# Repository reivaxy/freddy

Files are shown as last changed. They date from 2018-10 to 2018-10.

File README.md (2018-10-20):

# freddy

My goal was to design a set of pieces that are easy to print (no support is needed), and easy to assemble in order to build Freddy Krueger's famous clawed glove, so the design is simplified.

The claws (or blades) should be printed with grey or silver-like filament, and the finger pieces in brownish or bronze filament.

Each finger can be easily parametered with 2 diameters for each half finger, the lenghts of upper and lower fingers, and the length and width of the band to tie the finger to the hand plate.

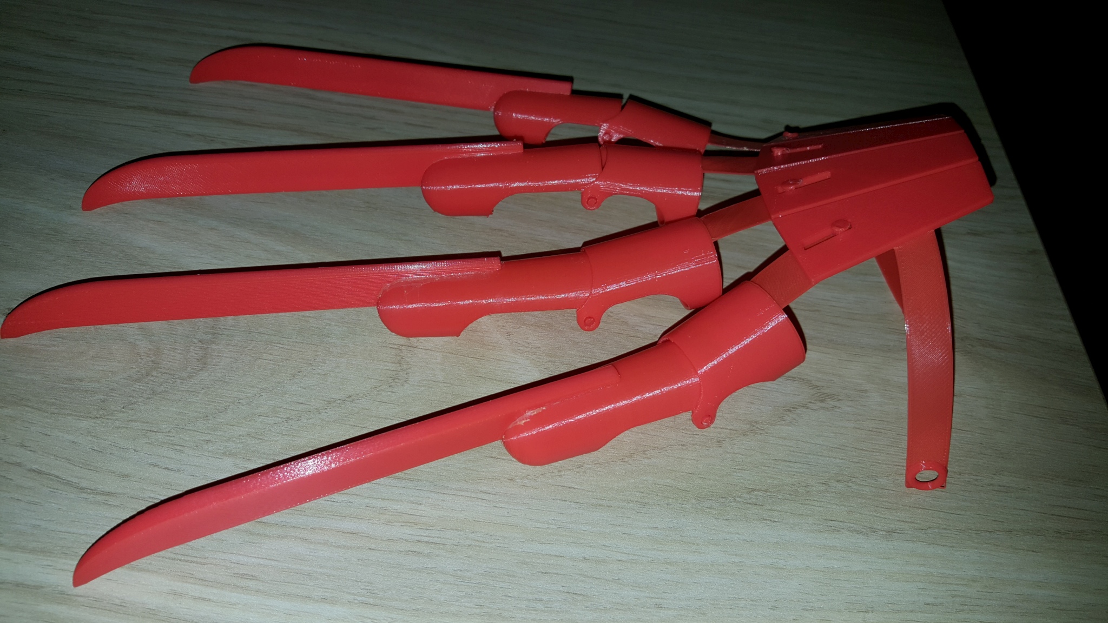
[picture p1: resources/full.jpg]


Here is the final print, using grey and bronze PLA, and wiping some acrylic paint on it so that it does not look to new.

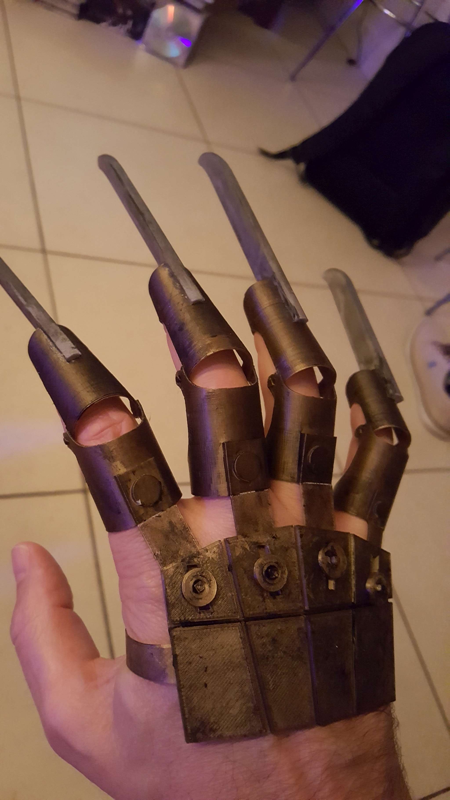
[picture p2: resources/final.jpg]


Admittedly, the sweater needs some work :)

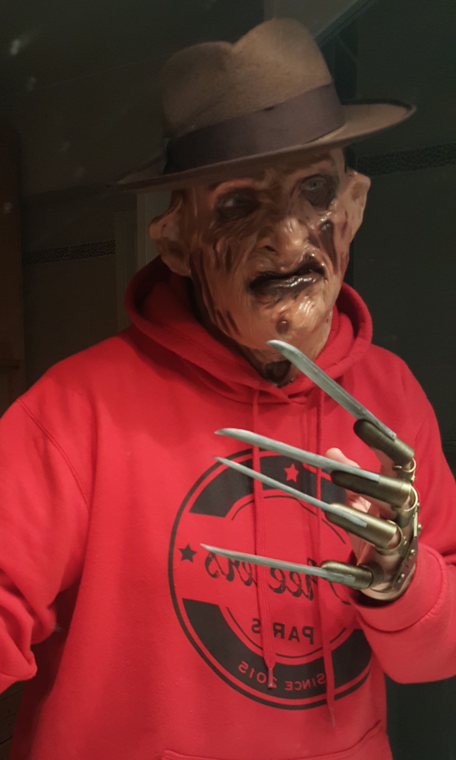
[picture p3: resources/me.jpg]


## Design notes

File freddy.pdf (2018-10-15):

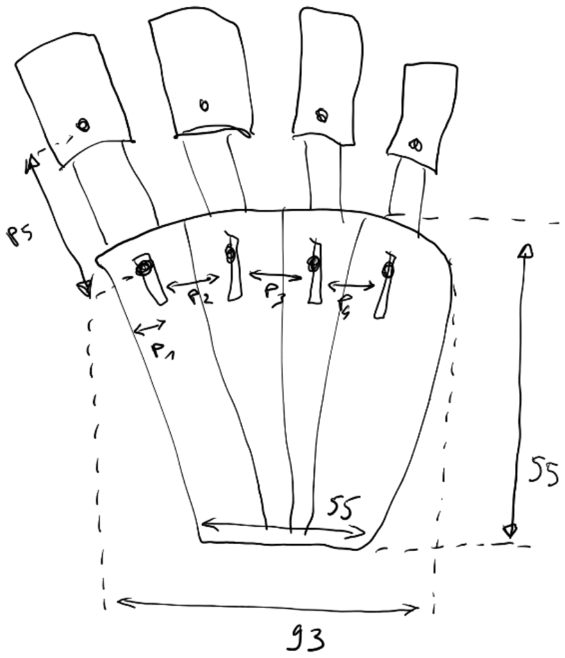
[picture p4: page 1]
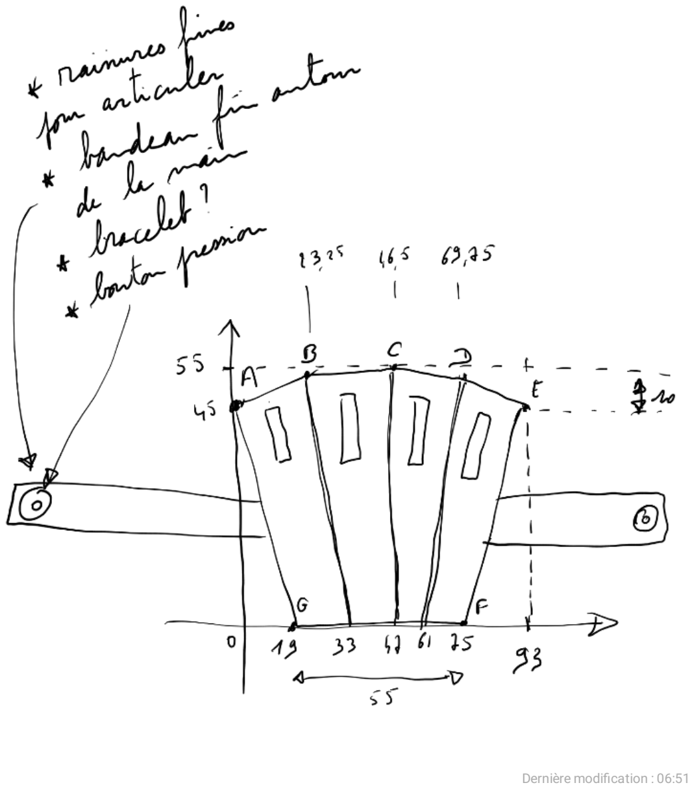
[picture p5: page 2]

Dernière modification : 06:51

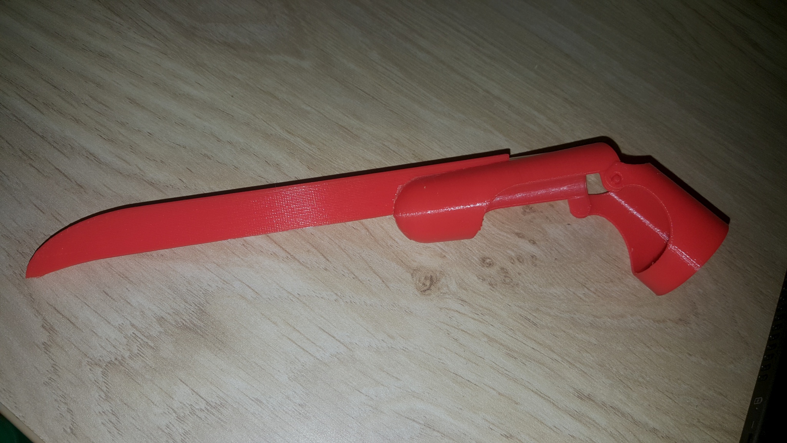
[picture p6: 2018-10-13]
resources/freddy.jpg

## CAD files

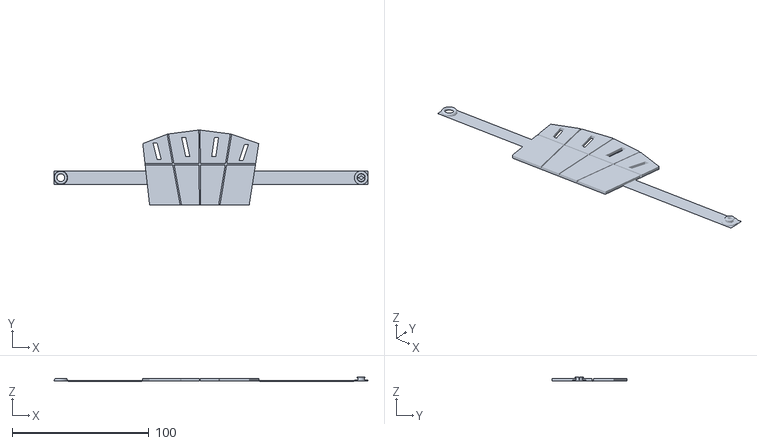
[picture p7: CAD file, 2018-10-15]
hand.stl
230.0 x 55.0 x 3.25

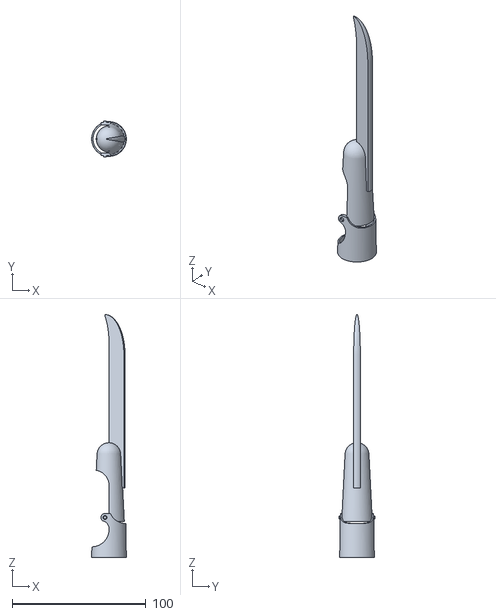
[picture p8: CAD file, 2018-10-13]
finger.stl
26.0 x 27.0 x 182.0

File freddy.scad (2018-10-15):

use <snapButton.scad>;

fingers();
translate([-50, -150, 0])
  handPlate();

module fingers() {
  translate([0, -70, 0])
    index();
  translate([0, -25, 0])
    majeur();
  translate([0, 20, 0])
    annulaire();
  translate([0, 65, 0])
    auriculaire();
}

// lowerBottomDiam, lowerTopDiam, lowerLength,
//          upperBottomDiam, upperTopDiam, upperLength,
//               join band width, join band length
module auriculaire() {
  printableFinger(20, 17, 33, 16, 15, 33, 8);
}
module annulaire() {
  printableFinger(23, 20, 34, 20, 16, 44);
}
module majeur() {
  printableFinger(24, 23, 40, 22, 16, 50);
}
module index() {
  printableFinger(24, 22, 33, 21, 16, 44);
  //finger(24, 23, 33, 21, 16, 44);
}

// thin band to join the base of each finger to the hand top plate
module join(width, length) {
  pinWidth = 2.5;
  color("yellow") {
    cube([length - width/2, width, 0.3]);
    translate([length - width/2, width/2, 0])
      cylinder(d=width, h=0.3, $fn=40);
    translate([length - 2*pinWidth, (width - pinWidth)/2, 0])
      cube([pinWidth, pinWidth, 6]);
  }

  // button to block it
  // snapButtonFemale(baseDiam, baseH, pinDiam, pinZ, tolerance=0.3)
  translate([length + 10 , width/2, 0])
   snapButtonFemale(10, 1.8, pinWidth, 3, tolerance=0.2);
}

module handPlate() {
  z = 2;
  zThin = 0.3;
  A = [5, 45];
  B = [23.25, 52];
  C = [46.5, 55];
  D = [69.75, 52];
  E = [90, 45];
  F = [83,0];
  G = [10, 0];
  difference() {
    linear_extrude(z)
      polygon([A, B, C, D, E, F, G]);

    // Creases for articulation
    crease(zThin, 1, B, [33, 0]);
    crease(zThin, 1, C, [47, 0]);
    crease(zThin, 1, D, [61, 0]);
    translate([0, 30, 0])
      rotate(90, [0, 0, -1])
        crease(zThin, 1, [0, 0], [0, 100]);

    // Creases for mobile finger joins
    crease(0, 3, [14,44], [17, 35]);
    crease(0, 3, [35,48], [38, 37]);
    crease(0, 3, [59,48], [57, 37]);
    crease(0, 3, [81,43], [77, 34]);
  }
  translate([-60, 15])
    wristBand(10, 230);
}

module crease(thin, width, topPoint, bottomPoint) {
  topPointLeft = [topPoint[0] - width/2, topPoint[1] + width/2];
  topPointRight = [topPoint[0] + width/2, topPoint[1] + width/2];
  bottomPointLeft = [bottomPoint[0] - width/2, bottomPoint[1] - width/2];
  bottomPointRight = [bottomPoint[0] + width/2, bottomPoint[1] - width/2];
  translate([0, 0, thin]) {
    linear_extrude(10) {
      polygon([topPointLeft, topPointRight, bottomPointRight, bottomPointLeft]);
    }
  }
}

thickness = 1;
hingeDiam = 3;
module printableFinger(lowerBottomDiam, lowerTopDiam, lowerLength,
                       upperBottomDiam, upperTopDiam, upperLength, joinWidth=13, joinLength=27) {

  //upperFinger(upperBottomDiam, upperTopDiam, upperLength, thickness, hingeDiam);
  translate([lowerBottomDiam + 5, 0, 0])
    lowerFinger(lowerBottomDiam, lowerTopDiam, lowerLength, thickness, hingeDiam, joinWidth, joinLength);
  translate([-40, 15, 0])
  rotate(90, [0, 0, 1])
  rotate(-10, [0, 1, 0])
  rotate(90, [1, 0, 0])
    claw(upperBottomDiam, upperTopDiam, upperLength);
}

module finger(lowerBottomDiam, lowerTopDiam, lowerLength,
                        upperBottomDiam, upperTopDiam, upperLength, joinWidth=13, joinLength=35) {
  lowerFinger(lowerBottomDiam, lowerTopDiam, lowerLength, thickness, hingeDiam, joinWidth, joinLength);
  translate([0, 0, lowerLength - 2* hingeDiam])
    upperFinger(upperBottomDiam, upperTopDiam, upperLength, thickness, hingeDiam);
  translate([-3, 0, upperLength+2])
    claw(upperBottomDiam, upperTopDiam, upperLength);
}

module claw(upperBottomDiam, upperTopDiam, upperLength) {
  difference() {
    rotate(90, [0, 0, 1]) {
      difference() {
        clawCore();
        translate([0, 12, 0])
          scale([3, 1, 1.09])
          clawCore();
        rotate(10, [0, 0, 1]) {
          translate([0, -20, 0])
            cube([20, 40, 150]);
        }
        rotate(-10, [0, 0, 1]) {
          translate([-20, -20, 0])
            cube([20, 40, 150]);
        }
      }
    }
    translate([2.6, 0, -upperLength/2]) {
      outerBottomDiameter = upperBottomDiam + 2* thickness;
      outerTopDiameter = upperTopDiam + 2* thickness;
      cylinder(d1 = outerBottomDiameter, d2 = outerTopDiameter, h = upperLength, $fn=50);
      // Top sphere
      translate([0, 0, upperLength]) {
        sphere(d=outerTopDiameter, $fn=50);
      }
    }
  }
}

module clawCore() {
  scale([1, 2, 1]) {
    translate([0, 0, 100])
      scale([1, 1, 4])
        sphere(d=15, $fn=100);
    cylinder(d=15, h=100, $fn=100);
  }
}

module upperFinger(innerBottomDiameter, innerTopDiameter, upperLength, thickness, hingeDiameter) {
  outerBottomDiameter = innerBottomDiameter + 2* thickness;
  outerTopDiameter = innerTopDiameter + 2* thickness;

  difference() {
    cylinder(d1 = outerBottomDiameter, d2 = outerTopDiameter, h = upperLength, $fn=100);
    cylinder(d1 = innerBottomDiameter, d2 = innerTopDiameter, h = upperLength, $fn=100);
    // Cut half of cylinder
    translate([-outerBottomDiameter, -outerBottomDiameter/2, 0]) {
      cube([outerBottomDiameter, outerBottomDiameter, upperLength - outerBottomDiameter]);
    }
    // Top of cut is rounded, which eases printing with no support
    color("blue")
    translate([-outerBottomDiameter/2, outerBottomDiameter/2, upperLength - outerBottomDiameter]) {
      rotate(90, [1, 0, 0]) {
        cylinder(d=outerBottomDiameter, h=outerBottomDiameter, $fn=100);
      }
    }
  }
  // Top sphere
  translate([0, 0, upperLength]) {
    difference() {
      sphere(d=outerTopDiameter, $fn=50);
      sphere(d=innerTopDiameter, $fn=50);
      // Cut lower half of sphere
      translate([-outerTopDiameter/2, -outerTopDiameter/2, -outerTopDiameter]) {
        cube(outerTopDiameter);
      }
    }
  }
  // Hinges to connect lower finger
  hingeSide = hingeDiameter * 2;
  translate([-hingeSide, -outerBottomDiameter/2, 0]) {
    difference() {
      union() {
        translate([hingeSide/2, 0, 0]) {
          cube([hingeSide/2, outerBottomDiameter, hingeSide]);
        }
        translate([hingeSide/2, outerBottomDiameter, hingeSide/2]) {
          rotate(90, [1, 0, 0]) {
            cylinder(d=hingeSide, h=outerBottomDiameter, $fn=100);
          }
        }
        hingeLength = 2;
        translate([hingeSide/2, outerBottomDiameter + hingeLength, hingeSide/2]) {
          rotate(90, [1, 0, 0]) {
            cylinder(d=hingeDiameter - 0.5, h=outerBottomDiameter + hingeLength*2, $fn=100);
          }
        }

      }
      translate([0, thickness, 0]) {
        cube([hingeSide, innerBottomDiameter, hingeSide*2]);
      }
    }
  }
}


module lowerFinger(innerBottomDiameter, innerTopDiameter, lowerLength,
                         thickness, hingeDiameter, joinWidth, joinLength) {
  outerBottomDiameter = innerBottomDiameter + 2* thickness;
  outerTopDiameter = innerTopDiameter + 2* thickness;

  difference() {
    union() {
      cylinder(d1 = outerBottomDiameter, d2 = outerTopDiameter, h = lowerLength, $fn=100);

      // Flat zone to attach the band to join the hand plate
      translate([0, -joinWidth/2, 0]) {
        color("blue")
        cube([outerBottomDiameter/2, joinWidth, joinWidth + 3]);
        // Add a fake rivet on the flat zone
        translate([outerBottomDiameter/2, joinWidth/2, (joinWidth + 3)/2])
          rotate(90, [0, 1, 0])
            cylinder(d=joinWidth*0.7, h=1, $fn=50);
      }
      // band to join the hand plate
      translate([outerBottomDiameter/2, -joinWidth/2, 0]) {
        join(joinWidth, joinLength);
      }
    }
    cylinder(d1 = innerBottomDiameter, d2 = innerTopDiameter, h = lowerLength, $fn=100);

    // Rounded cut in cylinder lower half, inner-hand
    color("red")
    translate([-outerBottomDiameter/2, outerBottomDiameter/2 + 5, lowerLength/5 + outerBottomDiameter/2]) {
      rotate(90, [1, 0, 0]) {
        cylinder(d = outerBottomDiameter, h = outerBottomDiameter + 10, $fn=100);
      }
    }
    // Remove cylinder inner-hand upper half
    color("blue")
    translate([-outerBottomDiameter, -outerBottomDiameter/2 - 1, 8 + outerBottomDiameter/2]) {
      cube([outerBottomDiameter, outerBottomDiameter + 2, lowerLength]);
    }
    // Rounded cut in cylinder upper half, outer-hand
    color("yellow")
    translate([outerTopDiameter/2, outerTopDiameter/2 + 5, lowerLength  + hingeDiameter + 2]) {
      rotate(90, [1, 0, 0]) {
        cylinder(d = outerTopDiameter, h = outerTopDiameter + 10, $fn=100);
      }
    }
  }
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

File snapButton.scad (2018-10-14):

snapTestOn();

module wristBand(width, length) {
  difference() {
    cube([length, width, 0.3]);
    translate([width/2, width/2, 0])
      cylinder(d=10, h=0.3, $fn=50);
  }
  translate([length-width/2, width/2, 0])
    snapButtonMale(width, 1, 5, 3);
  translate([width/2, width/2, 0]) {
    snapButtonFemale(width, 1, 5, 3);
  }

}

module snapTestOn() {
  snapButtonMale(10, 1, 4, 3);
  translate([0,0,1])
  snapButtonFemale(10, 1, 4, 3);
  translate([15, 0, 0]) {
    snapButtonMale(10, 1, 6, 3);
    translate([0,0,1])
    snapButtonFemale(10, 1, 6, 3);
  }
}

// Tolerance 0.2 is tight to the point of not being removable
module snapButtonFemale(baseDiam, baseH, pinDiam, pinZ, tolerance=0.3) {
  difference() {
    cylinder(d=baseDiam, h=baseH, $fn=50);
    cylinder(d=pinDiam + 2, h=pinZ, $fn=50);
  }
  translate([0, 0, (pinZ - 1) / 2]) {
    rotate_extrude(convexity = 10, $fn=50)
    translate([(pinDiam + pinZ - 1) / 2 + tolerance, 0, 0])
      circle(d=pinZ - 1, $fn = 50);
  }
}

module snapButtonMale(baseDiam, baseH, pinDiam, pinZ) {
  pinZ = pinZ*3/4;
  cylinder(d=baseDiam, h=baseH, $fn=50);
  translate([0, 0, baseH]) {
    difference() {
      union() {
        cylinder(d=pinDiam, h=pinZ, $fn=20);
        translate([0, 0, pinZ - 1/2]) {
          rotate_extrude(convexity = 10, $fn=50)
          translate([pinDiam/2, 0, 0])
          circle(d=1, $fn = 50);
        }
      }
      cylinder(d=pinDiam/2, h=pinZ+1, $fn=40);
      translate([-baseDiam/2, -0.25, 0])
        cube([baseDiam, 0.5, pinZ]);
    }
  }
}

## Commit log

2018-10-13 Begining of lower finger
    [freddy.scad]
2018-10-13 rounded cut to free the hinge for upper finger
    [freddy.scad]
2018-10-13 full finger
    [freddy.scad]
2018-10-13 Handling top and bottom diameters for lower finger. Begining of claw
    [freddy.scad]
2018-10-13 Claw ready for test print
    [freddy.scad]
2018-10-13 Finger + claw in one stl
    [freddy.scad, full.stl, index.stl]
2018-10-13 Parameters for all my fingers
    [freddy.scad]
2018-10-13 All fingers in one STL
    [finger.stl, freddy.scad]
2018-10-14 With snap button and wrist band prototype test print
    [freddy.scad]
2018-10-14 Added hand top with snap bracelet and finger joins
    [freddy.scad, hand.stl, index.stl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]
2018-10-15 Some adjustments
    [freddy.scad]
2018-10-15 finger to hand plate band now attached to finger base
    [freddy.scad, hand.stl, index.stl]
2018-10-15 Added snap button to block join band pin into hand plate slides
    [freddy.scad]
